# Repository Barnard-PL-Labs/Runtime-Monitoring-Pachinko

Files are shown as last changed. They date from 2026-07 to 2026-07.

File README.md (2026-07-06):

# Experiential Learning of Runtime Monitoring Using Pachinko

We present documentation of a classroom assignment that teaches runtime monitoring through a creative embedded systems build: an interactive Pachinko game. The assignment centers on a dual-core ESP32 workflow in which students write RTLola specifications for monitors, compile these monitors to C, and deploy them alongside sensor and actuator control logic. Pachinko game events are logged in real time and used to trigger sound, animation, and motor behavior according to formal temporal logic specifications.

This work showcases how formal methods can be taught in a hands-on, project-based setting for learners in a creative and classroom-scale setting. We also discuss portability: the assignment template, hardware stack, code base, and assessment approach are designed and documented to be replicated in other embedded systems, creative computing, or makerspace-style courses. This assignment was given to the students of Creative Embedded Systems (COMS3930) at Barnard College.

## Demo Video

<!--
  GitHub README does not render <iframe> embeds. Use one of the options below.

  Option A (recommended for GitHub): clickable thumbnail that opens YouTube.
  Replace VIDEO_ID with your YouTube video ID (the part after v= in the URL).
-->

Pachinko board demo (https://www.youtube.com/watch?v=MDFKCMT7R9U)

**Direct link:** [Watch on YouTube](https://www.youtube.com/watch?v=MDFKCMT7R9U)

<!--
  Option B: if you host this README elsewhere (e.g. a project website) that
  supports iframes, you can use:

  <iframe width="560" height="315"
    src="https://www.youtube.com/embed/VIDEO_ID"
    title="Pachinko runtime monitoring demo"
    frameborder="0"
    allow="accelerometer; autoplay; clipboard-write; encrypted-media; gyroscope; picture-in-picture; web-share"
    allowfullscreen>
  </iframe>
-->

---

# Ball logger and monitor ESP32

Pachinko board — overview

### Student projects

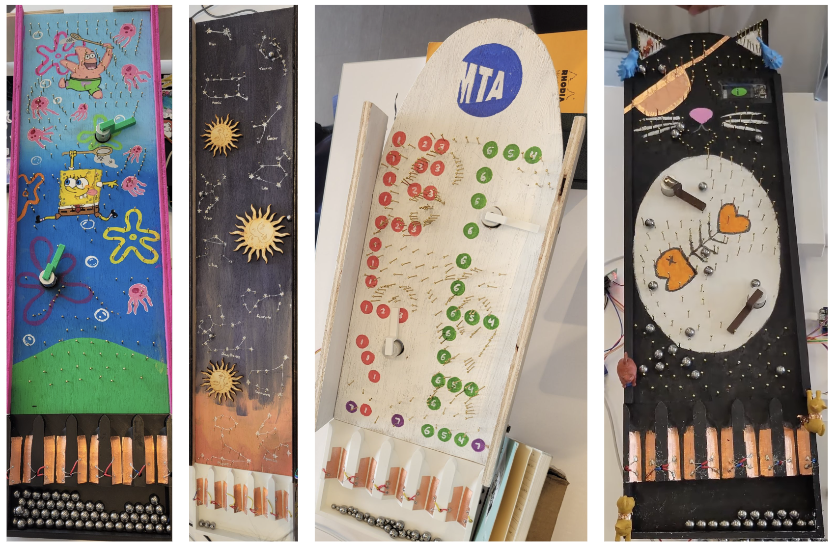
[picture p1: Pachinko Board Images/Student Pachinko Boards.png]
Student board 1


---

## Repository contents

- RTLola PlatformIO project folder that can run on ESP32 (does not include RTLola2C compiler)
- 3D models for pachinko ball logger, stepper motor mount, and motor arms
- Some images of an example pachinko board and wiring as well as boards made by students
- Full paper describing the assignment and its context

If you wish to gain access to the RTLola2C compiler to replicate this assignemnt, please contact Miles Scharff or Mark Santolucito

---

## License

© Miles Scharff, Maria Chemodanova, Mark Santolucito;
licensed under Creative Commons License CC-BY 4.0

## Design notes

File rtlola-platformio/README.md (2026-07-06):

# RTLola PlatformIO Project for ESP32

A streamlined workflow for compiling RTLola specifications and flashing them to ESP32 microcontrollers — all in one command.

## New Machine Setup

Setting up on a new machine? See **[SETUP.md](SETUP.md)** for detailed instructions, or run:

```bash
./scripts/setup.sh
```

## Sharing This Project

To share with others, use the distribution script:

```bash
./scripts/create_distribution.sh
```

This creates two zip files in `dist/`:
- `rtlola-esp32-binary.zip` — For same OS/architecture (includes pre-built compiler)
- `rtlola-esp32-source.zip` — For any platform (requires Rust to build compiler)

## Overview

This project automatically:
1. Detects `.lola` specification files in the `specs/` directory
2. Compiles them to C code using `rtlola2c`
3. Adapts the generated code for Arduino/ESP32
4. Builds the firmware and uploads to your ESP32

**One command does it all:** `pio run -t upload`

## Quick Start

### Prerequisites

1. **PlatformIO CLI** - Install via pip:
   ```bash
   pip install platformio
   ```
   Or use the [VS Code PlatformIO extension](https://platformio.org/install/ide?install=vscode).

2. **RTLola Compiler** - Build it from the parent directory:
   ```bash
   cd ../  # Go to rtlola directory
   cargo build --release
   ```
   This creates `target/release/rtlola2c`.

### Step 1: Add Your Specification

Create or copy your `.lola` file into the `specs/` directory:

```bash
# Example: copy an existing spec
cp ../in_place_drift.lola specs/

# Or create a new one
cat > specs/my_monitor.lola << 'EOF'
input temperature: Float64
input humidity: Float64

trigger temperature > 50.0 "Temperature too high!"
trigger humidity > 90.0 "Humidity too high!"
EOF
```

### Step 2: Update Your Code

Edit `src/main.cpp` to:
1. Include the correct monitor header (based on your spec filename)
2. Create events with the correct input fields
3. Handle the triggers from your spec

```cpp
// If your spec is specs/my_monitor.lola, include:
#include "rtlola_my_monitor/monitor.h"

// Create events matching your spec's inputs:
InternalEvent event = {
    .temperature = read_temp_sensor(),
    .temperature_is_present = true,
    .humidity = read_humidity_sensor(),
    .humidity_is_present = true,
    .time = millis() / 1000.0
};
```

### Step 3: Build and Upload

```bash
# Build only (single-core version)
pio run

# Build and upload
pio run -t upload

# Build dual-core version (for teaching runtime monitoring concepts)
pio run -e esp32dev-dualcore -t upload

# Upload and open serial monitor
pio run -t upload && pio device monitor
```

That's it! The pre-build script handles RTLola compilation automatically.

## Project Structure

```
rtlola-platformio/
├── platformio.ini          # PlatformIO configuration
├── specs/                   # Put your .lola files here
│   └── example_threshold.lola
├── src/
│   ├── main.cpp            # Single-core version
│   └── main_dual_core.cpp  # Dual-core version (pedagogical)
├── include/
│   └── rtlola_helpers.h    # Helper functions
├── lib/                     # Auto-generated monitors go here
│   └── rtlola_<spec_name>/ # Created by pre-build script
│       ├── monitor.cpp
│       ├── monitor.h
│       └── library.json
├── scripts/
│   ├── prebuild_rtlola.py  # Pre-build script (automatic)
│   ├── setup.sh            # Setup script for new machines
│   └── create_distribution.sh  # Create shareable archives
├── SETUP.md                # Detailed setup instructions
└── README.md
```

## Single-Core vs Dual-Core Versions

This project includes two versions:

### Single-Core (`main.cpp`)
- Simple, straightforward implementation
- Everything runs in `loop()` on one core
- Good for basic usage and getting started

### Dual-Core (`main_dual_core.cpp`)
- **Pedagogical version** demonstrating runtime monitoring concepts
- Core 0 = "System Under Test" (reads sensors, sends events)
- Core 1 = "Runtime Monitor" (runs RTLola, checks properties)
- Communication via FreeRTOS queue
- Shows separation between system and monitor

Use the dual-core version for teaching:
```bash
pio run -e esp32dev-dualcore -t upload
```

## Configuration

### Selecting Your ESP32 Board

Edit `platformio.ini` to change the board:

```ini
[env:esp32dev]
board = esp32dev          # Generic ESP32-WROOM

# Or use a specific board:
# board = esp32-s3-devkitc-1  # ESP32-S3
# board = esp32-c3-devkitm-1  # ESP32-C3
# board = adafruit_feather_esp32_v2
```

See all ESP32 boards: `pio boards espressif32`

### Enabling Optimization

For smaller code size, set the environment variable:

```bash
RTLOLA_OPTIMIZE=1 pio run -t upload
```

This passes `--optimize` to `rtlola2c`.

### Serial Port

If PlatformIO doesn't auto-detect your port:

```ini
[env:esp32dev]
upload_port = /dev/cu.usbserial-0001   # macOS
# upload_port = /dev/ttyUSB0           # Linux
# upload_port = COM3                    # Windows
```

## How It Works

### Pre-Build Script

The `scripts/prebuild_rtlola.py` script runs automatically before each build:

1. **Finds** all `.lola` files in `specs/`
2. **Compiles** each using `rtlola2c` from `../target/release/rtlola2c`
3. **Adapts** the generated C code for Arduino:
   - Replaces `stdio.h` with `Arduino.h`
   - Converts `printf()` to `Serial.printf()`
   - Adds `extern "C"` wrappers for C++ compatibility
4. **Outputs** to `lib/rtlola_<spec_name>/`

PlatformIO automatically discovers libraries in `lib/`, so the monitor is included in your build.

### Generated API

For each `.lola` spec, the compiler generates:

**InternalEvent struct** - Input to the monitor:
```c
typedef struct {
    double input_name;           // Your input stream
    bool input_name_is_present;  // Set true when providing this input
    double time;                 // Current timestamp in seconds
} InternalEvent;
```

**Verdict struct** - Output from the monitor:
```c
typedef struct {
    bool trigger_0_is_present;   // True if trigger 0 fired
    char* trigger_0;             // Trigger message (or NULL)
    bool trigger_1_is_present;   // True if trigger 1 fired
    char* trigger_1;             // Trigger message (or NULL)
    // ... more triggers
} Verdict;
```

**cycle() function** - Process an event:
```c
Verdict cycle(Memory* memory, InternalEvent event);
```

### Example Usage Pattern

```cpp
#include "rtlola_my_spec/monitor.h"

Memory memory;

void setup() {
    Serial.begin(115200);
    memset(&memory, 0, sizeof(memory));
}

void loop() {
    // Create event with current sensor values
    InternalEvent event = {
        .sensor_a = analogRead(A0) * 3.3 / 4095.0,
        .sensor_a_is_present = true,
        .sensor_b = analogRead(A1) * 3.3 / 4095.0,
        .sensor_b_is_present = true,
        .time = millis() / 1000.0
    };
    
    // Process through RTLola
    Verdict v = cycle(&memory, event);
    
    // React to triggers
    if (v.trigger_0_is_present) {
        digitalWrite(LED_PIN, HIGH);  // Alert!
        Serial.println(v.trigger_0);
    }
    
    delay(100);
}
```

## Multiple Specifications

You can have multiple `.lola` files in `specs/`. Each generates a separate library:

```
specs/
├── temperature_monitor.lola  → lib/rtlola_temperature_monitor/
├── motion_detector.lola      → lib/rtlola_motion_detector/
└── safety_limits.lola        → lib/rtlola_safety_limits/
```

Include multiple monitors in your code:
```cpp
#include "rtlola_temperature_monitor/monitor.h"
#include "rtlola_safety_limits/monitor.h"

Memory temp_memory, safety_memory;
// ... use each independently
```

## Troubleshooting

### "rtlola2c compiler not found"

Build the compiler:
```bash
cd ..  # Go to rtlola directory
cargo build --release
```

### "No .lola files found"

Ensure your specs are in the `specs/` directory with `.lola` extension.

### Compilation Errors in Generated Code

1. Check the `.lola` spec syntax
2. Try with `--optimize`: `RTLOLA_OPTIMIZE=1 pio run`
3. Check `lib/rtlola_<name>/monitor.h` for the correct struct names

### "undefined reference to cycle/Memory"

Make sure you're including the correct header for your spec:
- Spec: `specs/my_spec.lola`
- Include: `#include "rtlola_my_spec/monitor.h"`

### Serial Monitor Shows Garbage

Check baud rate matches: `pio device monitor -b 115200`

## VS Code Integration

If using the PlatformIO VS Code extension:

1. Open this folder in VS Code
2. PlatformIO will auto-detect the project
3. Use the PlatformIO toolbar buttons:
   - ✓ Build
   - → Upload
   - 🔌 Serial Monitor

The pre-build script runs automatically when you click Build or Upload.

## Supported RTLola Features

| Feature | Supported |
|---|---|
| Input streams | ✅ |
| Output streams | ✅ |
| Triggers | ✅ |
| Offset access `.offset(by:n)` | ✅ |
| Get access `.get()` | ✅ |
| Hold access `.hold()` | ✅ |
| Sync access | ✅ |
| `is_fresh()` checks | ✅ |
| Math functions | ✅ |
| Tuple types | ✅ |
| Conditionals | ✅ |
| Sliding windows | ❌ |
| Discrete windows | ❌ |
| Future access | ❌ |

## License

Same license as the parent RTLola project.

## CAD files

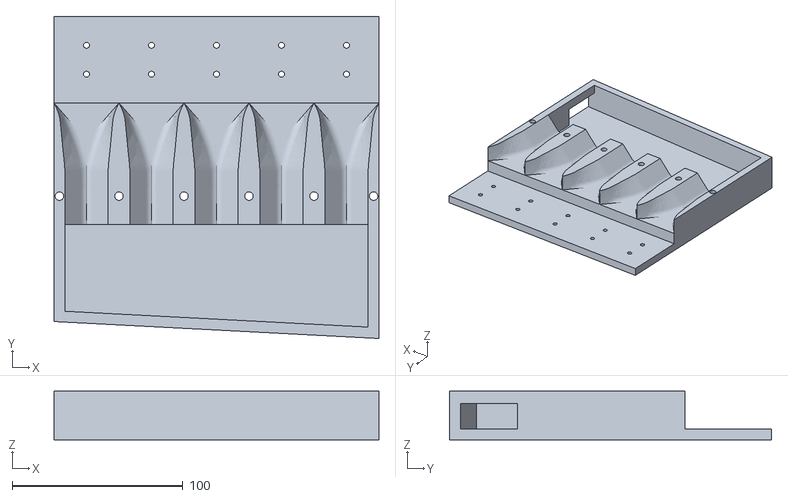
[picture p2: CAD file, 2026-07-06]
pachinko 3D models/pachinko logger v3.stl
190.5 x 188.7 x 28.6

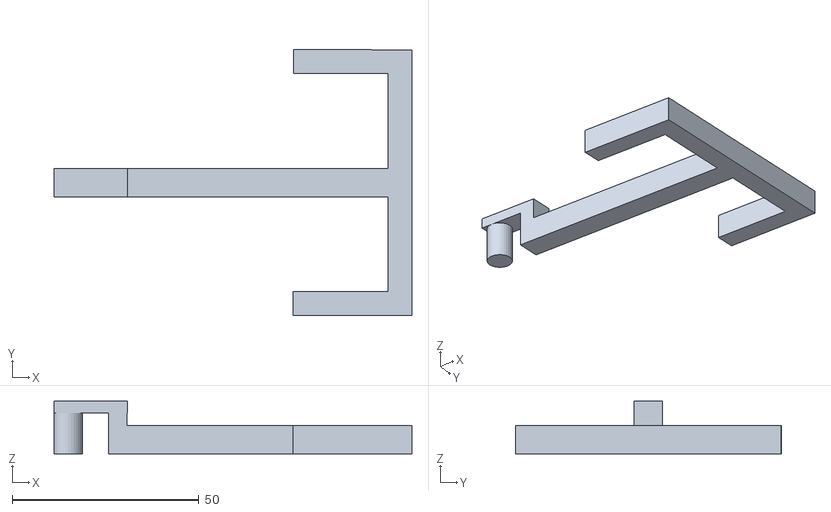
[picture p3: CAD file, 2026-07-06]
pachinko 3D models/motor arm pachinko v3.stl
95.9 x 71.1 x 14.2

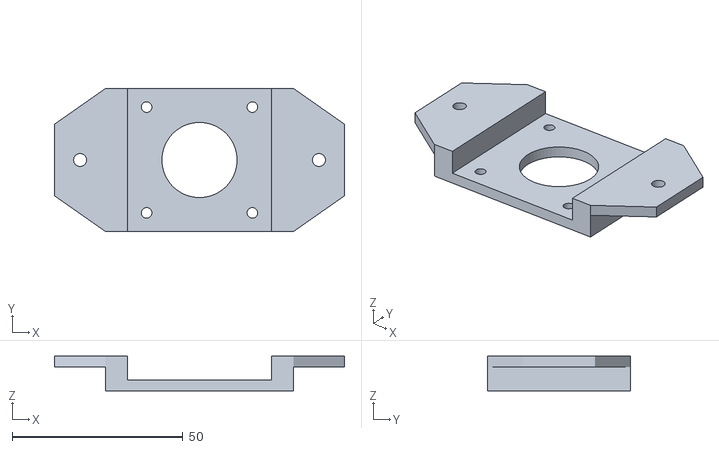
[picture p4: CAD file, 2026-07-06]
pachinko 3D models/stepper mount pachinko v1.stl
85.0 x 42.0 x 10.2

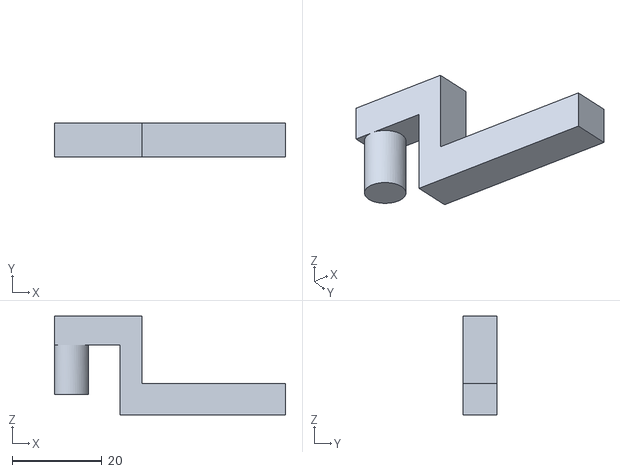
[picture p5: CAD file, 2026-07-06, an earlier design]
pachinko 3D models/motor arm pachinko v1.stl
51.6 x 7.60 x 22.1

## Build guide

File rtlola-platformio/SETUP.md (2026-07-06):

# RTLola ESP32 Project - Setup Guide

This guide explains how to set up the RTLola ESP32 monitoring project on a new machine.

## Prerequisites

### Required on All Platforms

1. **Python 3.8+**
   ```bash
   # Check if installed
   python3 --version
   ```

2. **PlatformIO CLI**
   ```bash
   # Install via pip
   pip install platformio
   
   # Or use the VS Code extension (recommended):
   # https://platformio.org/install/ide?install=vscode
   ```

3. **Git** (optional, for cloning)
   ```bash
   git --version
   ```

### Required Only If Building Compiler from Source

4. **Rust** (only needed if `rtlola2c` binary not provided)
   ```bash
   # Install Rust
   curl --proto '=https' --tlsv1.2 -sSf https://sh.rustup.rs | sh
   
   # Restart terminal, then verify
   rustc --version
   cargo --version
   ```

---

## Project Structure

```
rtlola/
├── Cargo.toml                    # Rust workspace config
├── Cargo.lock                    # Dependency lock file
├── rtlola2c/                     # Compiler source code
├── rtlola-streamir/              # Compiler dependency
├── target/
│   └── release/
│       └── rtlola2c              # Compiled binary (may need to build)
└── rtlola-platformio/            # ← YOU ARE HERE
    ├── platformio.ini            # PlatformIO config
    ├── src/
    │   ├── main.cpp              # Single-core version
    │   └── main_dual_core.cpp    # Dual-core version
    ├── specs/
    │   └── *.lola                # Your RTLola specifications
    ├── scripts/
    │   └── prebuild_rtlola.py    # Auto-compiles .lola files
    └── lib/                      # Auto-generated monitor code
```

---

## Setup Instructions

### Step 1: Get the Files

Either clone/copy the project or extract the provided archive:

```bash
# If you have a zip file
unzip rtlola-esp32-project.zip
cd rtlola

# If cloning from git
git clone <repository-url>
cd rtlola
```

### Step 2: Build the RTLola Compiler (If Needed)

Check if the compiler binary exists:

```bash
ls -la target/release/rtlola2c
```

**If the binary exists and you're on the same platform (OS/architecture):**
Skip to Step 3.

**If the binary doesn't exist or you're on a different platform:**

```bash
# Make sure you're in the rtlola directory (parent of rtlola-platformio)
cd rtlola

# Build the compiler (requires Rust)
cargo build --release

# Verify it built successfully
./target/release/rtlola2c --help
```

You should see help output like:
```
RTLola to C compiler
Usage: rtlola2c [OPTIONS] <SPEC>
...
```

### Step 3: Install PlatformIO Dependencies

```bash
cd rtlola-platformio

# PlatformIO will auto-download ESP32 toolchain on first build
# Just run a build to trigger this:
pio run
```

This will:
1. Download the ESP32 Arduino framework
2. Run the pre-build script (compiles your `.lola` specs)
3. Build the firmware

### Step 4: Connect Your ESP32 and Upload

```bash
# List available serial ports
pio device list

# Upload to ESP32
pio run -t upload

# Open serial monitor to see output
pio device monitor
```

---

## Quick Commands Reference

| Action | Command |
|---|---|
| Build firmware | `pio run` |
| Build + Upload | `pio run -t upload` |
| Serial monitor | `pio device monitor` |
| Build dual-core version | `pio run -e esp32dev-dualcore` |
| Upload dual-core version | `pio run -e esp32dev-dualcore -t upload` |
| Clean build | `pio run -t clean` |
| List serial ports | `pio device list` |

---

## Adding Your Own Specifications

1. Create a `.lola` file in `specs/`:
   ```bash
   nano specs/my_monitor.lola
   ```

2. Write your specification:
   ```lola
   input temperature: Float64
   input pressure: Float64
   
   trigger temperature > 100.0 "Too hot!"
   trigger pressure < 50.0 "Pressure low!"
   ```

3. Update `src/main.cpp` to include the generated header:
   ```cpp
   #include "rtlola_my_monitor/monitor.h"
   ```

4. Update the `InternalEvent` struct to match your inputs:
   ```cpp
   InternalEvent event = {
       .temperature = read_temp(),
       .temperature_is_present = true,
       .pressure = read_pressure(),
       .pressure_is_present = true,
       .time = millis() / 1000.0
   };
   ```

5. Build and upload:
   ```bash
   pio run -t upload
   ```

---

## Troubleshooting

### "rtlola2c compiler not found"

Build the compiler:
```bash
cd ..  # Go to rtlola directory
cargo build --release
```

### "cargo: command not found"

Install Rust:
```bash
curl --proto '=https' --tlsv1.2 -sSf https://sh.rustup.rs | sh
source ~/.cargo/env
```

### "pio: command not found"

Install PlatformIO:
```bash
pip install platformio
```

### Serial port permission denied (Linux)

Add yourself to the dialout group:
```bash
sudo usermod -a -G dialout $USER
# Log out and back in
```

### Upload fails / ESP32 not detected

1. Check the USB cable (some are charge-only)
2. Install drivers if needed:
   - CP210x: https://www.silabs.com/developers/usb-to-uart-bridge-vcp-drivers
   - CH340: https://www.wch-ic.com/downloads/CH341SER_ZIP.html
3. Try holding BOOT button while uploading

### Build errors in generated monitor code

1. Check your `.lola` spec syntax
2. Try with optimization: `RTLOLA_OPTIMIZE=1 pio run`
3. Look at the generated `lib/rtlola_<name>/monitor.h` for correct struct names

---

## Platform-Specific Notes

### macOS

- If using Apple Silicon (M1/M2/M3), the pre-built binary must also be ARM64
- Serial ports appear as `/dev/cu.usbserial-*` or `/dev/cu.SLAB_USBtoUART`

### Windows

- Serial ports appear as `COM3`, `COM4`, etc.
- May need to install CH340 or CP210x drivers
- Use PowerShell or Git Bash for commands

### Linux

- Serial ports appear as `/dev/ttyUSB0` or `/dev/ttyACM0`
- Add user to `dialout` group for serial access
- May need to install `python3-venv` for PlatformIO

---

## Version Information

- PlatformIO Core: 6.x
- ESP32 Arduino Core: 2.x
- Rust: 1.70+ (if building compiler)
- Python: 3.8+

---

## Support

For issues with:
- **RTLola language**: https://rtlola.org/
- **PlatformIO**: https://docs.platformio.org/
- **ESP32 Arduino**: https://docs.espressif.com/projects/arduino-esp32/

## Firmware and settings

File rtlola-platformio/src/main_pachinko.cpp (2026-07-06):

/**
 * RTLola ESP32 Monitor - Pachinko Ball Detection
 * 
 * OVERVIEW:
 * =========
 * This dual-core implementation monitors 5 pachinko ball sensors using RTLola
 * for runtime verification. Ball detection uses non-blocking debouncing with
 * rising-edge detection.
 * 
 * ARCHITECTURE:
 * =============
 * 
 *   ┌─────────────────────────────┐              ┌─────────────────────────────┐
 *   │  CORE 0: Sensor System      │              │  CORE 1: RTLola Monitor     │
 *   │                             │              │                             │
 *   │  • Read 5 analog sensors    │   Event      │  • Receive ball events      │
 *   │  • Debounce (200ms)         │   Queue      │  • Run RTLola cycle()       │
 *   │  • Detect rising edges ─────────────────►  │  • Check triggers           │
 *   │  • Send ball events         │              │  • Detect patterns:         │
 *   │                             │              │    - Simultaneous balls     │
 *   │  • Receive flags ◄──────────────────────── │    - Repeated triggers      │
 *   │  • React to violations      │   Flag       │    - Unusual sequences      │
 *   │                             │   Queue      │                             │
 *   └─────────────────────────────┘              └─────────────────────────────┘
 * 
 * HARDWARE:
 * =========
 * - 5 ball sensors on ADC1 pins: GPIO 36, 39, 34, 35, 32
 * - Each sensor bridges contacts when a ball passes
 * - Analog threshold detection with debouncing
 * 
 * USAGE:
 * ======
 * 1. Update specs/pachinko.lola with your monitoring rules
 * 2. Build: pio run -e esp32dev-pachinko -t upload
 * 3. Monitor: pio device monitor
 */

#include <Arduino.h>
#include <string.h>
#include <freertos/FreeRTOS.h>
#include <freertos/task.h>
#include <freertos/queue.h>

// Include the generated RTLola monitor for pachinko spec
// The monitor.h is in lib/rtlola_pachinko/ (generated from specs/pachinko.lola)
// We use a direct path since PlatformIO's LDF may not find it on first build
#include "../lib/rtlola_pachinko/monitor.h"

// ============================================================================
// Hardware Configuration
// ============================================================================

#define SERIAL_BAUD 115200

// Sensor pins (ADC1-capable GPIOs on ESP32)
static const int SENSOR_COUNT = 5;
static const uint8_t SENSOR_PINS[SENSOR_COUNT] = { 36, 39, 34, 35, 32 };

// Detection parameters
static const int THRESHOLD = 1000;              // Analog threshold for ball detection
static const unsigned long DEBOUNCE_MS = 200;   // Debounce time per sensor

// ============================================================================
// Task Configuration
// ============================================================================

#define SYSTEM_STACK_SIZE 4096
#define MONITOR_STACK_SIZE 4096
#define EVENT_QUEUE_SIZE 20     // Buffer for ball events
#define FLAG_QUEUE_SIZE 10      // Buffer for monitor flags

// System runs at high frequency for responsive ball detection
#define SYSTEM_LOOP_MS 5        // 200Hz sensor polling

// ============================================================================
// Flag Types - Messages from Monitor to System
// ============================================================================
// 
// These are generic flag types that students can assign meaning to.
// For example:
//   FLAG_TYPE_1 = "send to display ESP32"
//   FLAG_TYPE_2 = "send to sound ESP32"
//   FLAG_TYPE_3 = "log to SD card"
//   FLAG_TYPE_4 = "broadcast to all"
//

typedef enum {
    FLAG_TYPE_0 = 0,
    FLAG_TYPE_1,
    FLAG_TYPE_2,
    FLAG_TYPE_3,
    FLAG_TYPE_4
} FlagType;

typedef struct {
    FlagType type;
    uint8_t trigger_id;     // Which trigger fired (0, 1, 2, ...)
    double timestamp;       // When the violation occurred
    char message[64];       // Human-readable message
} MonitorFlag;

// ============================================================================
// Global Variables
// ============================================================================

// Queues for inter-core communication
QueueHandle_t eventQueue;       // System → Monitor (ball events)
QueueHandle_t flagQueue;        // Monitor → System (alerts)

// Task handles
TaskHandle_t systemTaskHandle;
TaskHandle_t monitorTaskHandle;

// Statistics
volatile uint32_t total_balls_detected = 0;
volatile uint32_t balls_per_channel[SENSOR_COUNT] = {0};
volatile uint32_t events_sent = 0;
volatile uint32_t events_processed = 0;
volatile uint32_t flags_received = 0;

// ============================================================================
// CORE 0: Sensor System
// ============================================================================

// Per-sensor state for debouncing
struct SensorState {
    unsigned long lastTriggerMs;
    bool wasAbove;
};

static SensorState sensorStates[SENSOR_COUNT];

// Current cycle's ball detection (true = ball detected this cycle)
static bool ballDetected[SENSOR_COUNT];

/**
 * Initialize sensor states
 */
void initSensors() {
    for (int i = 0; i < SENSOR_COUNT; i++) {
        sensorStates[i].lastTriggerMs = 0;
        sensorStates[i].wasAbove = false;
        ballDetected[i] = false;
    }
}

/**
 * Read all sensors with non-blocking debounce.
 * Uses rising-edge detection so held contacts don't repeat.
 * 
 * After this function, ballDetected[i] is true if sensor i
 * just detected a ball this cycle (and wasn't in debounce).
 */
void readAllSensors() {
    const unsigned long now = millis();
    
    for (int i = 0; i < SENSOR_COUNT; i++) {
        const int raw = analogRead(SENSOR_PINS[i]);
        const bool above = (raw > THRESHOLD);
        
        // Reset detection flag each cycle
        ballDetected[i] = false;
        
        // Rising edge: crossed threshold upward
        if (above && !sensorStates[i].wasAbove) {
            // Check debounce
            if (now - sensorStates[i].lastTriggerMs >= DEBOUNCE_MS) {
                sensorStates[i].lastTriggerMs = now;
                ballDetected[i] = true;
                
                // Update statistics
                total_balls_detected++;
                balls_per_channel[i]++;
                
                // Log detection
                Serial.printf("[SENSOR] Ball on channel %d (GPIO %d) raw=%d\n", 
                              i, SENSOR_PINS[i], raw);
            }
        }
        
        sensorStates[i].wasAbove = above;
    }
}

/**
 * Handle a flag received from the monitor.
 * 
 * Students can customize what happens for each flag type.
 * For example, different types could send to different ESP32s via ESP-NOW.
 */
void handleMonitorFlag(MonitorFlag& flag) {
    flags_received++;

    Serial.printf("[SYSTEM] Flag received: type=%d, trigger=%d, msg=%s\n",
                  flag.type, flag.trigger_id, flag.message);

    // ════════════════════════════════════════════════════════════════════
    // THIS IS WHERE YOU PUT ESP-NOW CODE TO RESPOND TO FLAGS FROM THE MONITOR
    // 
    // Example: esp_now_send(peer_mac, (uint8_t*)&flag, sizeof(flag));
    // ════════════════════════════════════════════════════════════════════
    
    switch (flag.type) {
        case FLAG_TYPE_0:
            Serial.printf("[SYSTEM] Type 0: %s\n", flag.message);
            break;
            
        case FLAG_TYPE_1:
            Serial.printf("[SYSTEM] Type 1: %s\n", flag.message);
            break;
            
        case FLAG_TYPE_2:
            Serial.printf("[SYSTEM] Type 2: %s\n", flag.message);
            break;
            
        case FLAG_TYPE_3:
            Serial.printf("[SYSTEM] Type 3: %s\n", flag.message);
            break;
            
        case FLAG_TYPE_4:
            Serial.printf("[SYSTEM] Type 4: %s\n", flag.message);
            break;
            
        default:
            break;
    }
}

/**
 * System Task - runs on Core 0
 * 
 * Reads all 5 sensors with non-blocking debounce and sends
 * ball detection events to the RTLola monitor on Core 1.
 */
void systemTask(void* parameter) {
    Serial.println("[SYSTEM] Task started on Core 0");
    Serial.printf("[SYSTEM] Monitoring %d sensors at %dHz\n", 
                  SENSOR_COUNT, 1000/SYSTEM_LOOP_MS);
    Serial.printf("[SYSTEM] Pins: ");
    for (int i = 0; i < SENSOR_COUNT; i++) {
        Serial.printf("%d ", SENSOR_PINS[i]);
    }
    Serial.println();
    
    // Initialize sensor states
    initSensors();
    
    TickType_t lastWakeTime = xTaskGetTickCount();
    const TickType_t period = pdMS_TO_TICKS(SYSTEM_LOOP_MS);
    
    while (true) {
        // ─────────────────────────────────────────────────────────────
        // Step 1: Read all sensors (non-blocking with debounce)
        // ─────────────────────────────────────────────────────────────
        readAllSensors();
        
        // ─────────────────────────────────────────────────────────────
        // Step 2: Create event for RTLola monitor
        // Send 1.0 if ball detected, 0.0 otherwise
        // ─────────────────────────────────────────────────────────────
        InternalEvent event = {
            .sensor_1 = ballDetected[0] ? 1.0 : 0.0,
            .sensor_1_is_present = true,
            .sensor_2 = ballDetected[1] ? 1.0 : 0.0,
            .sensor_2_is_present = true,
            .sensor_3 = ballDetected[2] ? 1.0 : 0.0,
            .sensor_3_is_present = true,
            .sensor_4 = ballDetected[3] ? 1.0 : 0.0,
            .sensor_4_is_present = true,
            .sensor_5 = ballDetected[4] ? 1.0 : 0.0,
            .sensor_5_is_present = true,
            .time = millis() / 1000.0
        };
        
        // Only send if at least one ball was detected (reduces queue traffic)
        // Remove this check if you want continuous monitoring
        bool anyBall = ballDetected[0] || ballDetected[1] || ballDetected[2] || 
                       ballDetected[3] || ballDetected[4];
        
        if (anyBall) {
            if (xQueueSend(eventQueue, &event, 0) == pdTRUE) {
                events_sent++;
            }
        }
        
        // ─────────────────────────────────────────────────────────────
        // Step 3: Check for flags from monitor (non-blocking)
        // ─────────────────────────────────────────────────────────────
        MonitorFlag flag;
        while (xQueueReceive(flagQueue, &flag, 0) == pdTRUE) {
            handleMonitorFlag(flag);
        }
        
        // Run at fixed frequency
        vTaskDelayUntil(&lastWakeTime, period);
    }
}

// ============================================================================
// CORE 1: RTLola Monitor
// ============================================================================

Memory rtlola_memory;

/**
 * Send a flag to the system.
 * 
 * @param type       The flag type (FLAG_TYPE_0 through FLAG_TYPE_4)
 * @param trigger_id Which RTLola trigger fired (0, 1, 2, ...)
 * @param timestamp  When the trigger fired
 * @param message    Human-readable message from the trigger
 */
void sendFlag(FlagType type, uint8_t trigger_id, 
              double timestamp, const char* message) {
    MonitorFlag flag;
    flag.type = type;
    flag.trigger_id = trigger_id;
    flag.timestamp = timestamp;
    strncpy(flag.message, message, sizeof(flag.message) - 1);
    flag.message[sizeof(flag.message) - 1] = '\0';
    
    xQueueSend(flagQueue, &flag, 0);
}

/**
 * Handle RTLola verdict - check triggers and send flags.
 * 
 * Each trigger maps to a flag type. Students can customize this mapping
 * based on what action they want each trigger to produce.
 */
void handleVerdict(Verdict& verdict, double event_time) {
    // Trigger 0: Multiple balls simultaneously → Flag Type 0
    if (verdict.trigger_0_is_present) {
        Serial.printf("[MONITOR] Trigger 0 at t=%.2f\n", event_time);
        sendFlag(FLAG_TYPE_0, 0, event_time, 
                 verdict.trigger_0 ? verdict.trigger_0 : "Multiple simultaneous balls!");
    }
    
    // Trigger 1: Same channel twice in a row → Flag Type 1
    if (verdict.trigger_1_is_present) {
        Serial.printf("[MONITOR] Trigger 1 at t=%.2f\n", event_time);
        sendFlag(FLAG_TYPE_1, 1, event_time,
                 verdict.trigger_1 ? verdict.trigger_1 : "Repeated channel trigger");
    }
    
    // Trigger 2: Edge channels (1 and 5) at same time → Flag Type 2
    if (verdict.trigger_2_is_present) {
        Serial.printf("[MONITOR] Trigger 2 at t=%.2f\n", event_time);
        sendFlag(FLAG_TYPE_2, 2, event_time,
                 verdict.trigger_2 ? verdict.trigger_2 : "Edge channels triggered");
    }
    
    // Trigger 3: Three or more balls at once → Flag Type 3
    if (verdict.trigger_3_is_present) {
        Serial.printf("[MONITOR] Trigger 3 at t=%.2f\n", event_time);
        sendFlag(FLAG_TYPE_3, 3, event_time,
                 verdict.trigger_3 ? verdict.trigger_3 : "Too many simultaneous balls!");
    }
    
    // Trigger 4: Center channel (3) triggered → Flag Type 4
    if (verdict.trigger_4_is_present) {
        Serial.printf("[MONITOR] Trigger 4 at t=%.2f\n", event_time);
        sendFlag(FLAG_TYPE_4, 4, event_time,
                 verdict.trigger_4 ? verdict.trigger_4 : "Center channel hit!");
    }
    
    // Add more triggers as defined in your pachinko.lola spec
}

/**
 * Monitor Task - runs on Core 1
 */
void monitorTask(void* parameter) {
    Serial.println("[MONITOR] Task started on Core 1");
    
    // Initialize RTLola monitor
    memset(&rtlola_memory, 0, sizeof(rtlola_memory));
    Serial.println("[MONITOR] RTLola monitor initialized");
    
    InternalEvent event;
    
    while (true) {
        // Wait for ball events from system
        if (xQueueReceive(eventQueue, &event, portMAX_DELAY) == pdTRUE) {
            events_processed++;
            
            // Process through RTLola
            Verdict verdict = cycle(&rtlola_memory, event);
            
            // Check for violations and send flags
            handleVerdict(verdict, event.time);
        }
    }
}

// ============================================================================
// Status Reporting Task
// ============================================================================

void statusTask(void* parameter) {
    while (true) {
        vTaskDelay(pdMS_TO_TICKS(10000));  // Every 10 seconds
        
        Serial.println("\n════════════════════════════════════════════════════════════");
        Serial.println("           PACHINKO MONITOR STATUS");
        Serial.println("════════════════════════════════════════════════════════════");
        Serial.printf("  Total balls detected: %lu\n", total_balls_detected);
        Serial.println("  Per-channel counts:");
        for (int i = 0; i < SENSOR_COUNT; i++) {
            Serial.printf("    Channel %d (GPIO %d): %lu balls\n", 
                          i, SENSOR_PINS[i], balls_per_channel[i]);
        }
        Serial.println("  Communication:");
        Serial.printf("    Events sent:      %lu\n", events_sent);
        Serial.printf("    Events processed: %lu\n", events_processed);
        Serial.printf("    Flags received:   %lu\n", flags_received);
        Serial.printf("  Free heap: %u bytes\n", ESP.getFreeHeap());
        Serial.println("════════════════════════════════════════════════════════════\n");
    }
}

// ============================================================================
// Setup
// ============================================================================

void setup() {
    Serial.begin(SERIAL_BAUD);
    while (!Serial && millis() < 3000) {
        delay(10);
    }
    
    Serial.println("\n");
    Serial.println("╔════════════════════════════════════════════════════════════╗");
    Serial.println("║     PACHINKO BALL MONITOR - RTLola Runtime Verification    ║");
    Serial.println("╠════════════════════════════════════════════════════════════╣");
    Serial.println("║                                                            ║");
    Serial.println("║  Core 0: Sensor System                                     ║");
    Serial.println("║    • Reads 5 ball sensors (non-blocking)                   ║");
    Serial.println("║    • Debounced edge detection                              ║");
    Serial.println("║    • Sends ball events to monitor                          ║");
    Serial.println("║                                                            ║");
    Serial.println("║  Core 1: RTLola Monitor                                    ║");
    Serial.println("║    • Verifies ball patterns                                ║");
    Serial.println("║    • Detects anomalies (jams, multiple balls, etc.)        ║");
    Serial.println("║    • Sends flags back to system                            ║");
    Serial.println("║                                                            ║");
    Serial.println("╚════════════════════════════════════════════════════════════╝");
    Serial.println();
    
    // Create queues
    eventQueue = xQueueCreate(EVENT_QUEUE_SIZE, sizeof(InternalEvent));
    flagQueue = xQueueCreate(FLAG_QUEUE_SIZE, sizeof(MonitorFlag));
    
    if (!eventQueue || !flagQueue) {
        Serial.println("ERROR: Failed to create queues!");
        while (1) { delay(1000); }
    }
    Serial.println("[SETUP] Queues created");
    
    // Create tasks on separate cores
    xTaskCreatePinnedToCore(systemTask, "SensorSystem", SYSTEM_STACK_SIZE,
                            NULL, 1, &systemTaskHandle, 0);  // Core 0
    
    xTaskCreatePinnedToCore(monitorTask, "RTLolaMonitor", MONITOR_STACK_SIZE,
                            NULL, 1, &monitorTaskHandle, 1);  // Core 1
    
    xTaskCreate(statusTask, "Status", 2048, NULL, 0, NULL);
    
    Serial.println("[SETUP] Tasks created");
    Serial.println("\n[SETUP] Pachinko monitoring started!\n");
    Serial.println("Drop some balls to see detection and RTLola verification.\n");
}

void loop() {
    vTaskDelay(pdMS_TO_TICKS(1000));
}

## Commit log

2026-07-06 Rename Body1.stl to motor arm pachinko v1.stl
    [motor arm pachinko v1.stl]
2026-07-06 Update board overview section in README
